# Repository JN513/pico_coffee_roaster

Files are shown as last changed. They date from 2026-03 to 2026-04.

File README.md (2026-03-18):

# Pico Coffee Roaster

Mini torrador de café baseado no Raspberry Pi Pico.

Este firmware é capaz de realizar o controle de uma resistência utilizando um triac, além do controle de um motor e de um fan via PWM.
Também estão disponíveis periféricos como displays, termistores NTC, termopares PT0, controle PID, entre outros.

O projeto utiliza o pico-sdk como base.
Além do pico-sdk instalado e configurado no PATH do ambiente, também é necessário instalar o pico-extras.

## Build e load

Para compilar o projeto utilize:

```bash
mkdir -p build
cd build
cmake ..
make -j$(nproc)
```

Para enviar o firmware para o Pico utilize:

```bash
cd build
picotool load pico_roster.uf2 -f
```

Certifique-se de que o `picotool` esteja instalado e disponível no PATH do sistema.

## Dúvidas e Sugestões

Se tiver alguma dúvida ou sugestão, sinta-se à vontade para utilizar a seção de [ISSUES](https://github.com/JN513/pico_coffee_roaster/issues) no GitHub. Contribuições são bem-vindas e todos os [Pull requests](https://github.com/JN513/pico_coffee_roaster/pulls) serão revisados e, se possível, mesclados.

## Contribuição

Se deseja contribuir com o projeto, sinta-se à vontade para fazê-lo. O arquivo [CONTRIBUTING.md](https://github.com/JN513/pico_coffee_roaster/blob/main/CONTRIBUTING.md) contém as instruções necessárias.

## Licença

Este projeto é licenciado sob a licença [MIT]([https://github.com/JN513/pico_coffee_roaster/blob/main/LICENSE](https://github.com/JN513/pico_coffee_roaster/blob/main/LICENSE)), que concede total liberdade para uso.

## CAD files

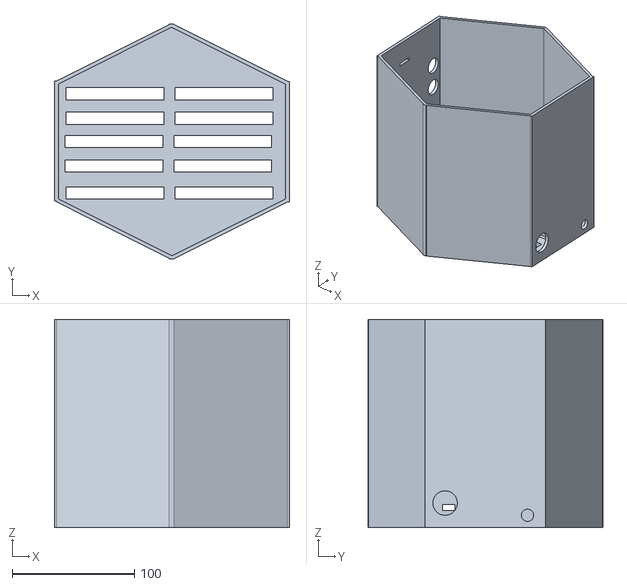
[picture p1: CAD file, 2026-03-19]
hardware/3d_models/roaster_case.stl
192.0 x 192.0 x 170.0

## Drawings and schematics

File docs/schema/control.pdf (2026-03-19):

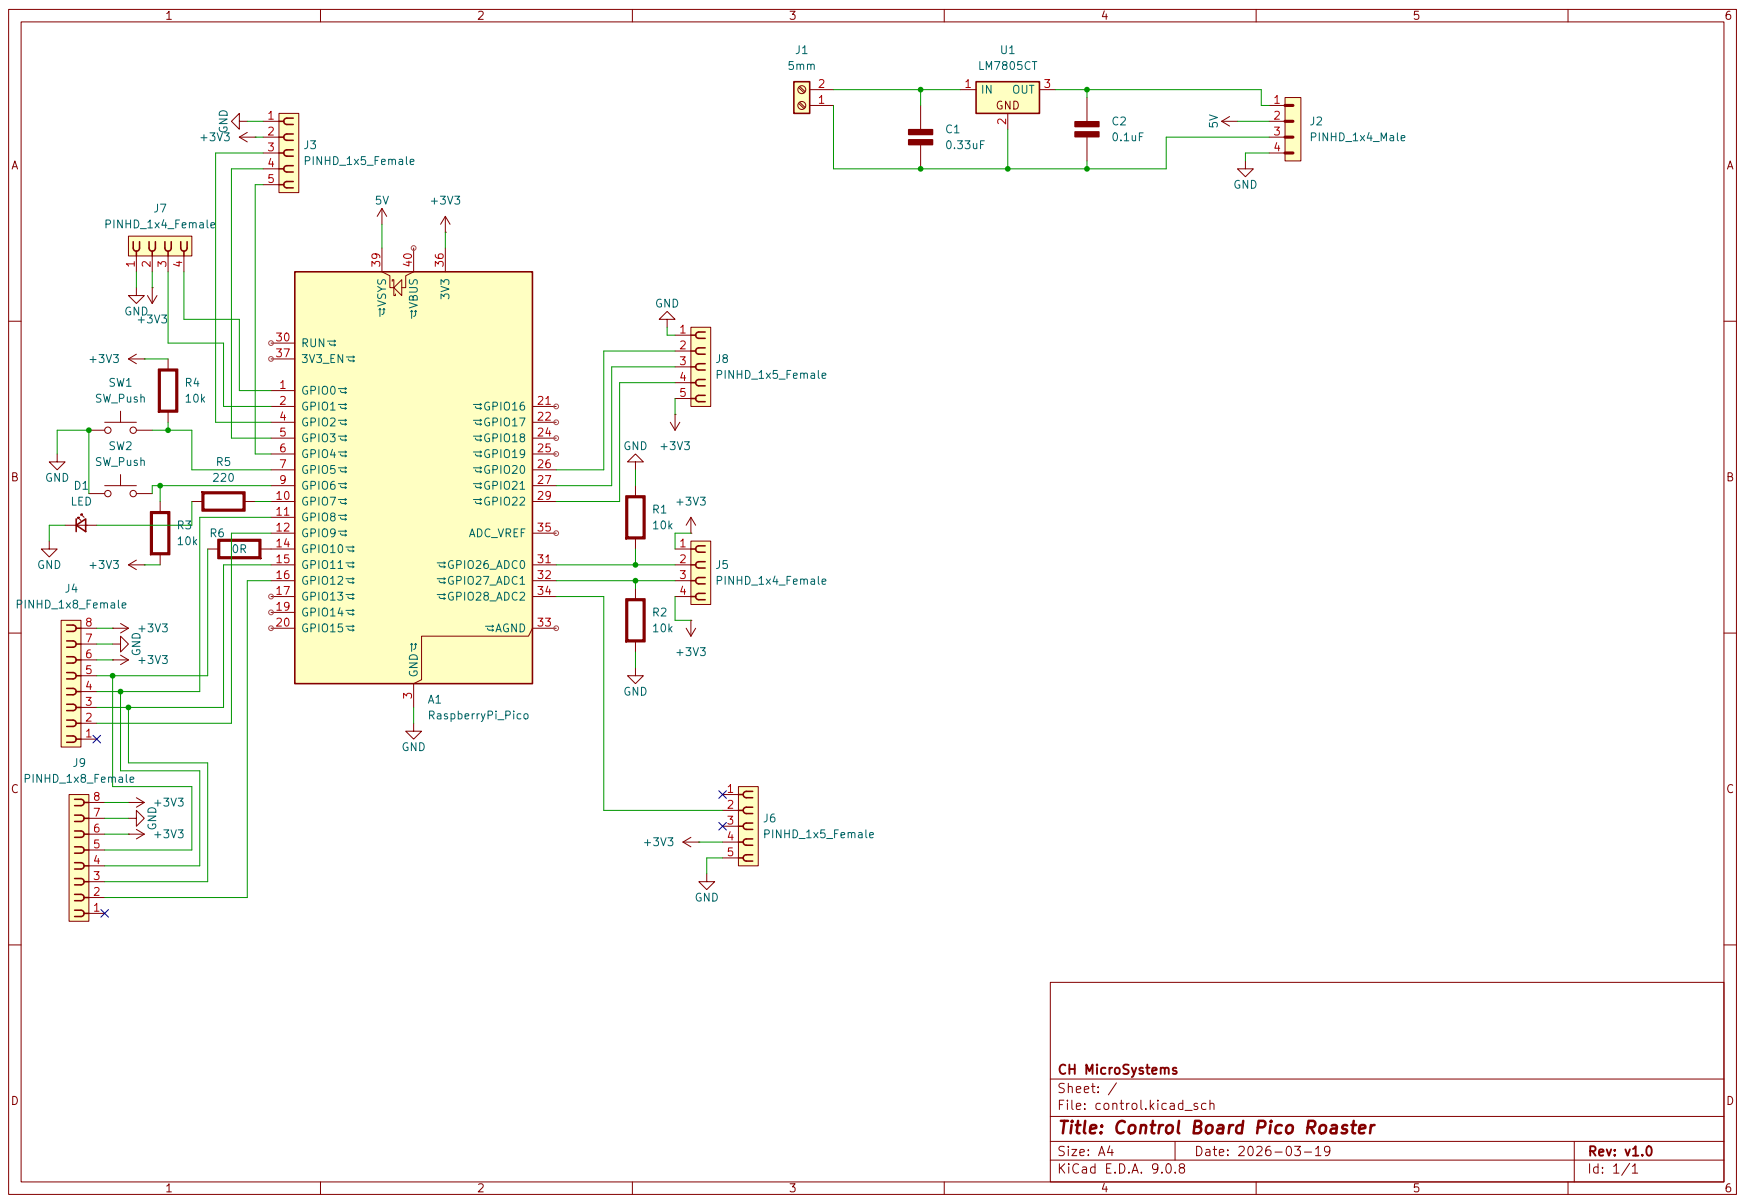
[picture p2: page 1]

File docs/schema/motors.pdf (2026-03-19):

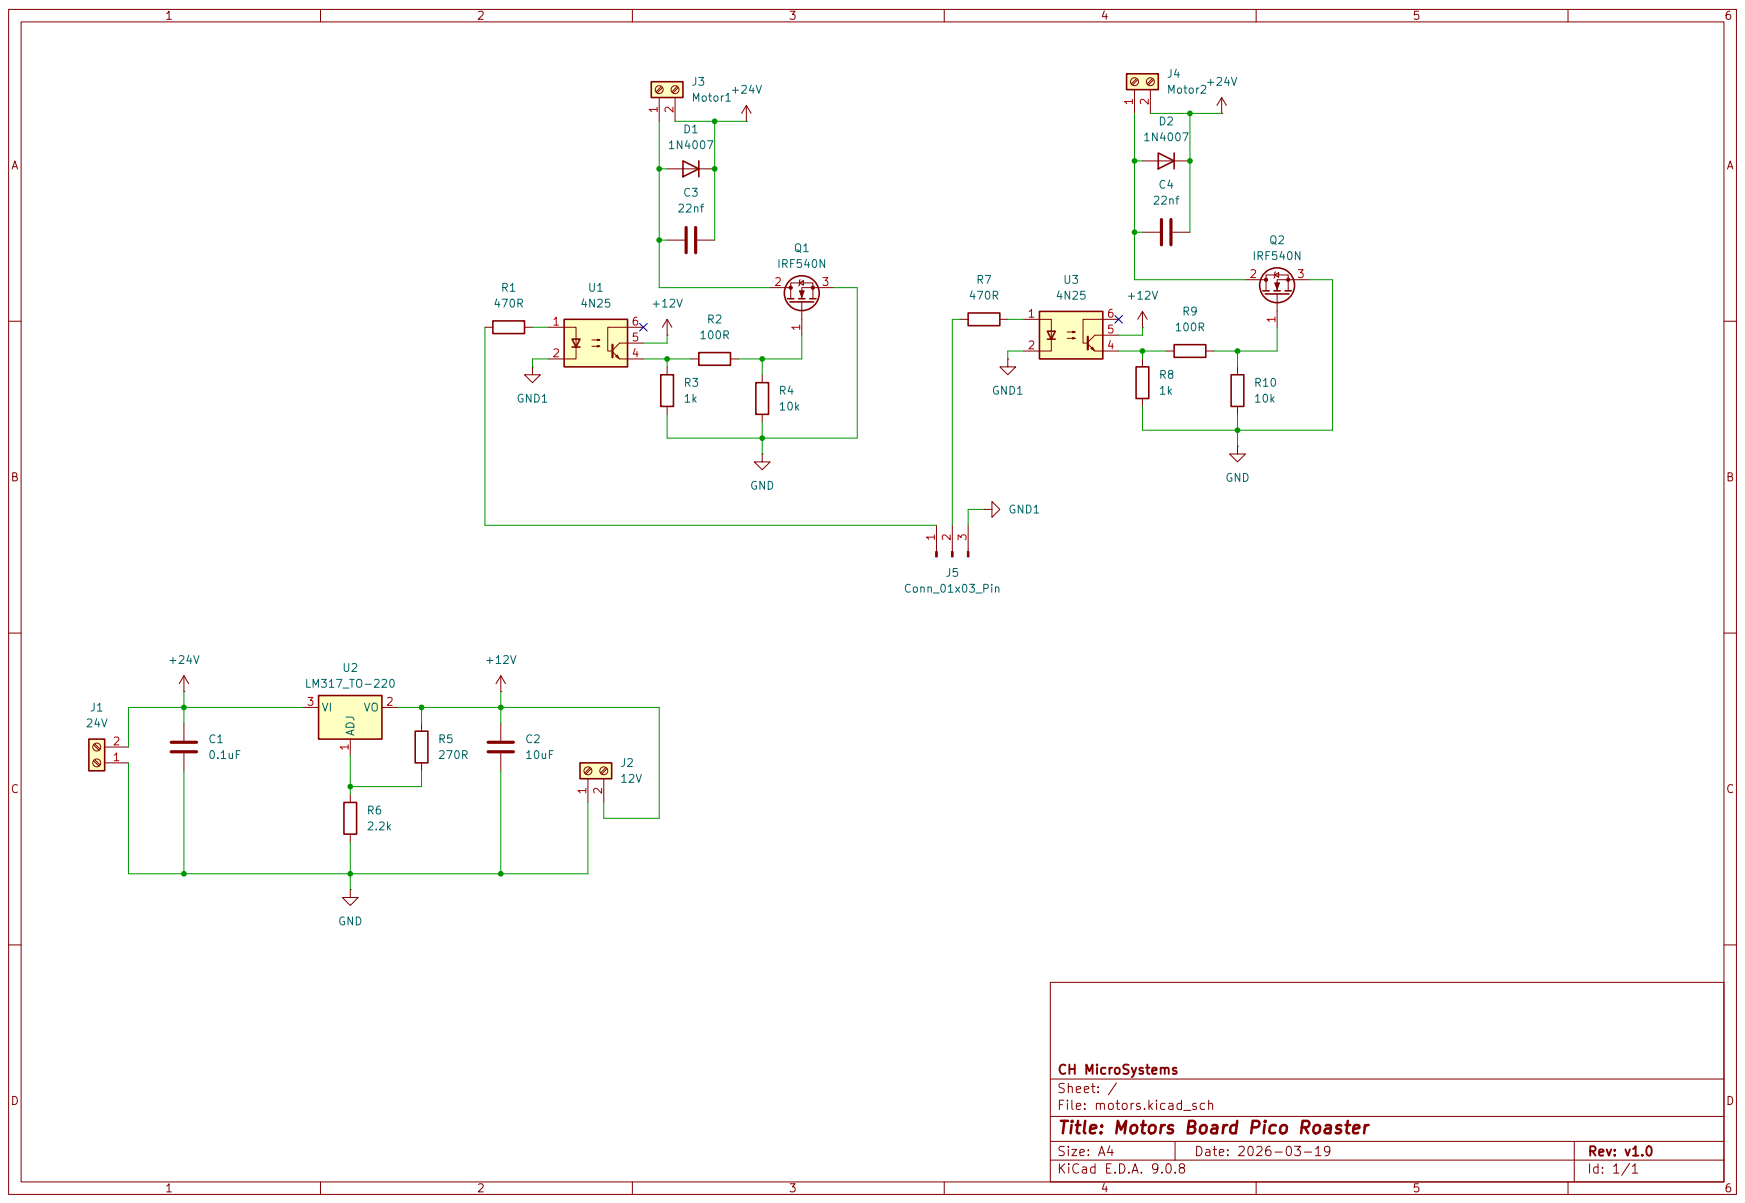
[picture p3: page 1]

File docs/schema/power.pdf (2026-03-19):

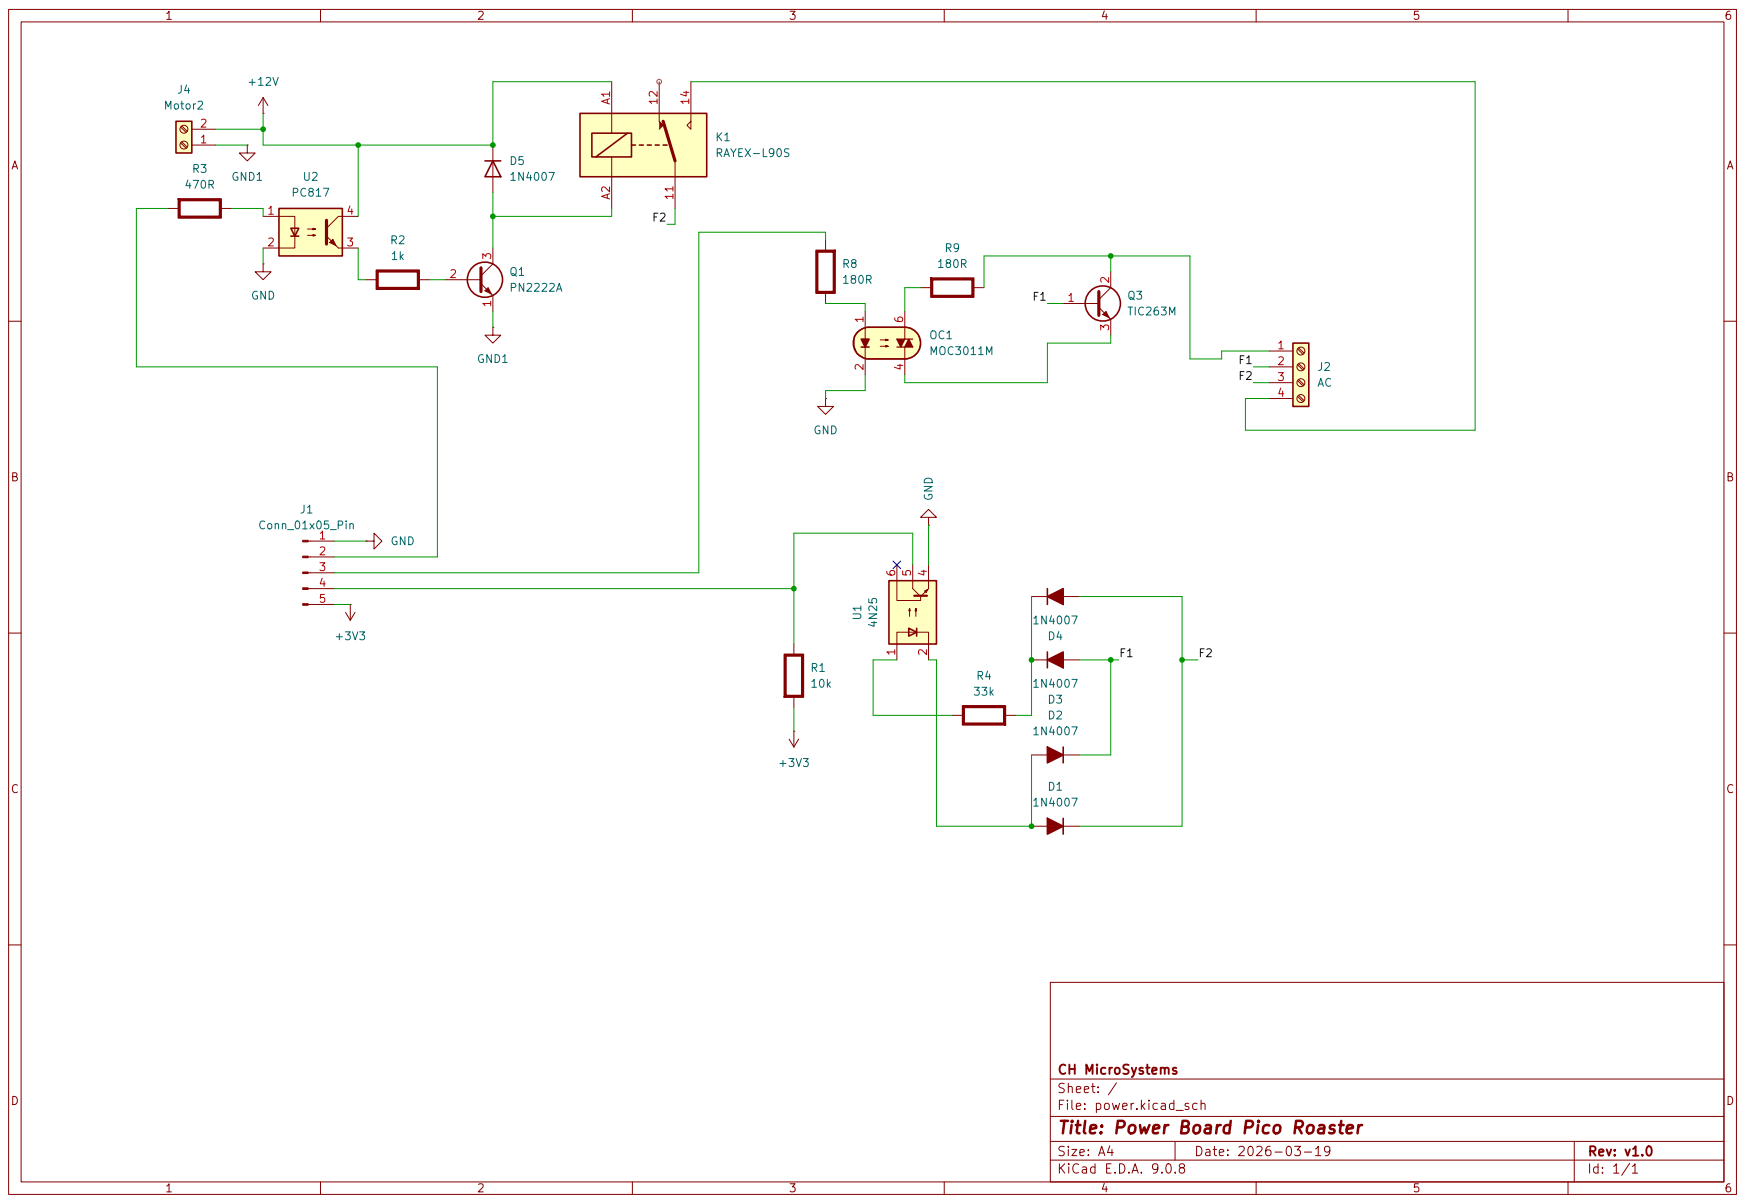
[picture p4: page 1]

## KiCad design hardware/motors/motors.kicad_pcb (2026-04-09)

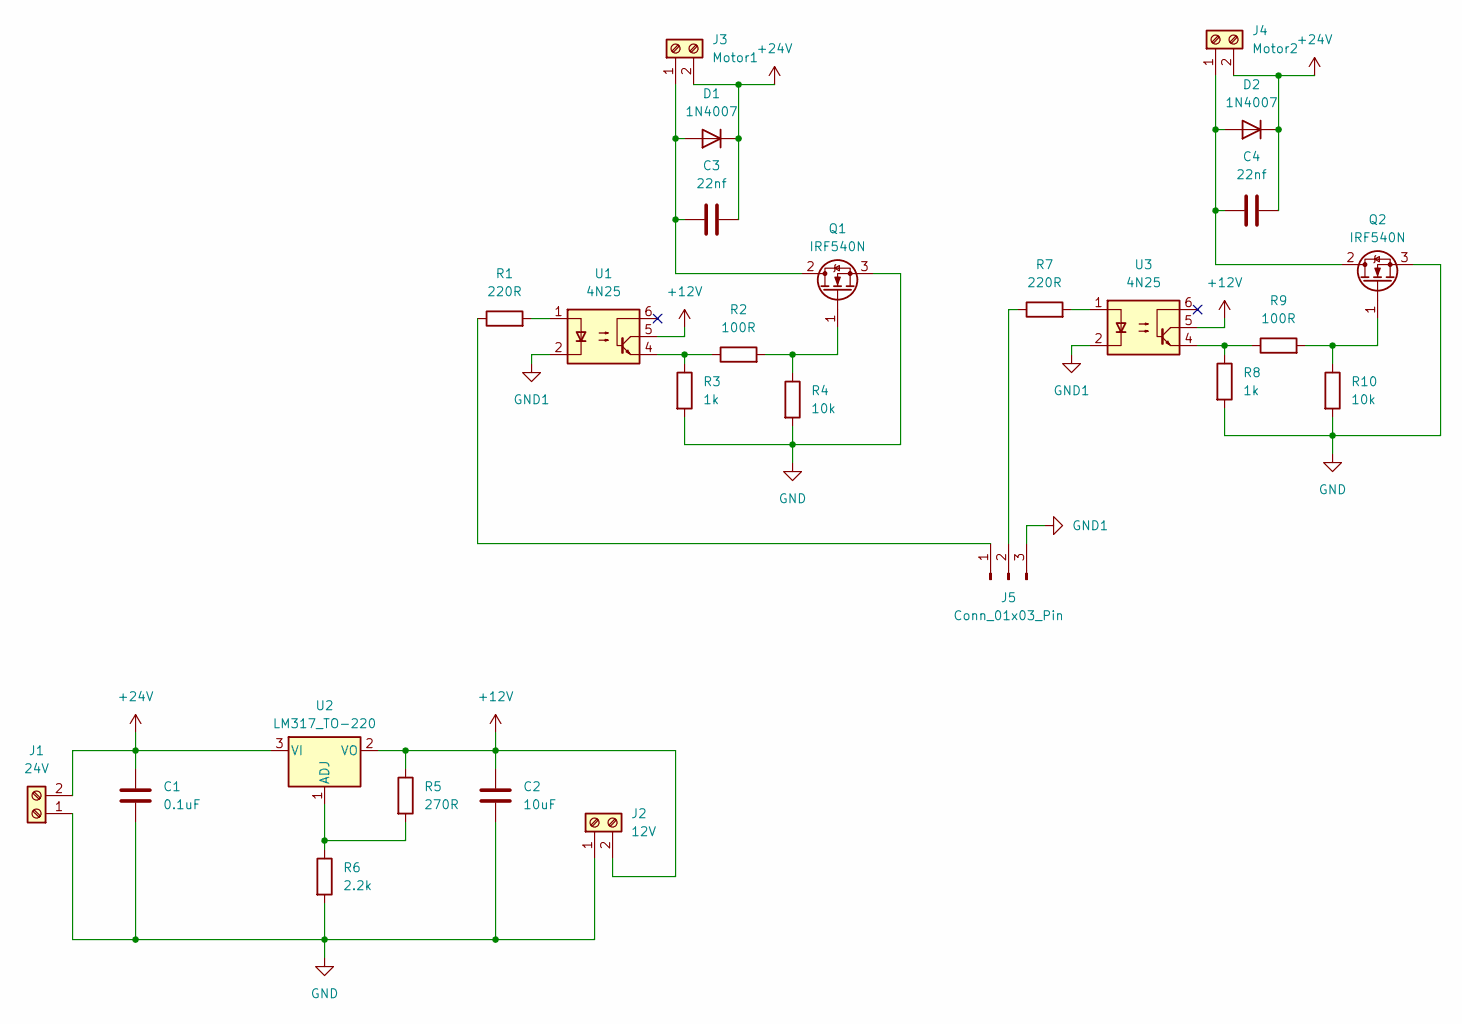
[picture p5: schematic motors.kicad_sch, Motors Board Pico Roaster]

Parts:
C1: 0.1uF; CP_Radial_D4.0mm_P2.00mm
C2: 10uF; CP_Radial_D4.0mm_P2.00mm
C3, C4: 22nf; C_Disc_D4.7mm_W2.5mm_P5.00mm
D1, D2: 1N4007; D_DO-41_SOD81_P10.16mm_Horizontal
J1: 24V; Altech_AK100_1x02_P5.00mm
J2: 12V; Altech_AK100_1x02_P5.00mm
J3: Motor1; Altech_AK100_1x02_P5.00mm
J4: Motor2; Altech_AK100_1x02_P5.00mm
J5: Conn_01x03_Pin; PinHeader_1x03_P2.54mm_Vertical
Q1, Q2: IRF540N; TO-220-3_Vertical
R1, R7: 220R; R_Axial_DIN0204_L3.6mm_D1.6mm_P7.62mm_Horizontal
R2, R9: 100R; R_Axial_DIN0204_L3.6mm_D1.6mm_P7.62mm_Horizontal
R3, R8: 1k; R_Axial_DIN0204_L3.6mm_D1.6mm_P7.62mm_Horizontal
R4, R10: 10k; R_Axial_DIN0204_L3.6mm_D1.6mm_P7.62mm_Horizontal
R5: 270R; R_Axial_DIN0204_L3.6mm_D1.6mm_P7.62mm_Horizontal
R6: 2.2k; R_Axial_DIN0204_L3.6mm_D1.6mm_P7.62mm_Horizontal
U1, U3: 4N25; DIP-6_W7.62mm
U2: LM317_TO-220; TO-220-3_Vertical

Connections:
+12V: C2.1, J2.2, R5.1, U1.5, U2.2 (VO), U3.5
+24V: C1.1, C3.2, C4.2, D1.1 (K), D2.1 (K), J1.2, J3.2, J4.2, U2.3 (VI)
GND: C1.2, C2.2, J1.1, J2.1, Q1.3 (S), Q2.3 (S), R3.2, R4.2, R6.2, R8.2, R10.2
GND1: J5.3, U1.2, U3.2
unnamed: C3.1, D1.2 (A), J3.1, Q1.2 (D)
unnamed: C4.1, D2.2 (A), J4.1, Q2.2 (D)
unnamed: J5.1, R1.1
unnamed: J5.2, R7.1
unnamed: Q1.1 (G), R2.2, R4.1
unnamed: Q2.1 (G), R9.2, R10.1
unnamed: R1.2, U1.1
unnamed: R2.1, R3.1, U1.4
unnamed: R7.2, U3.1
unnamed: R8.1, R9.1, U3.4
unnamed: R5.2, R6.1, U2.1 (ADJ)

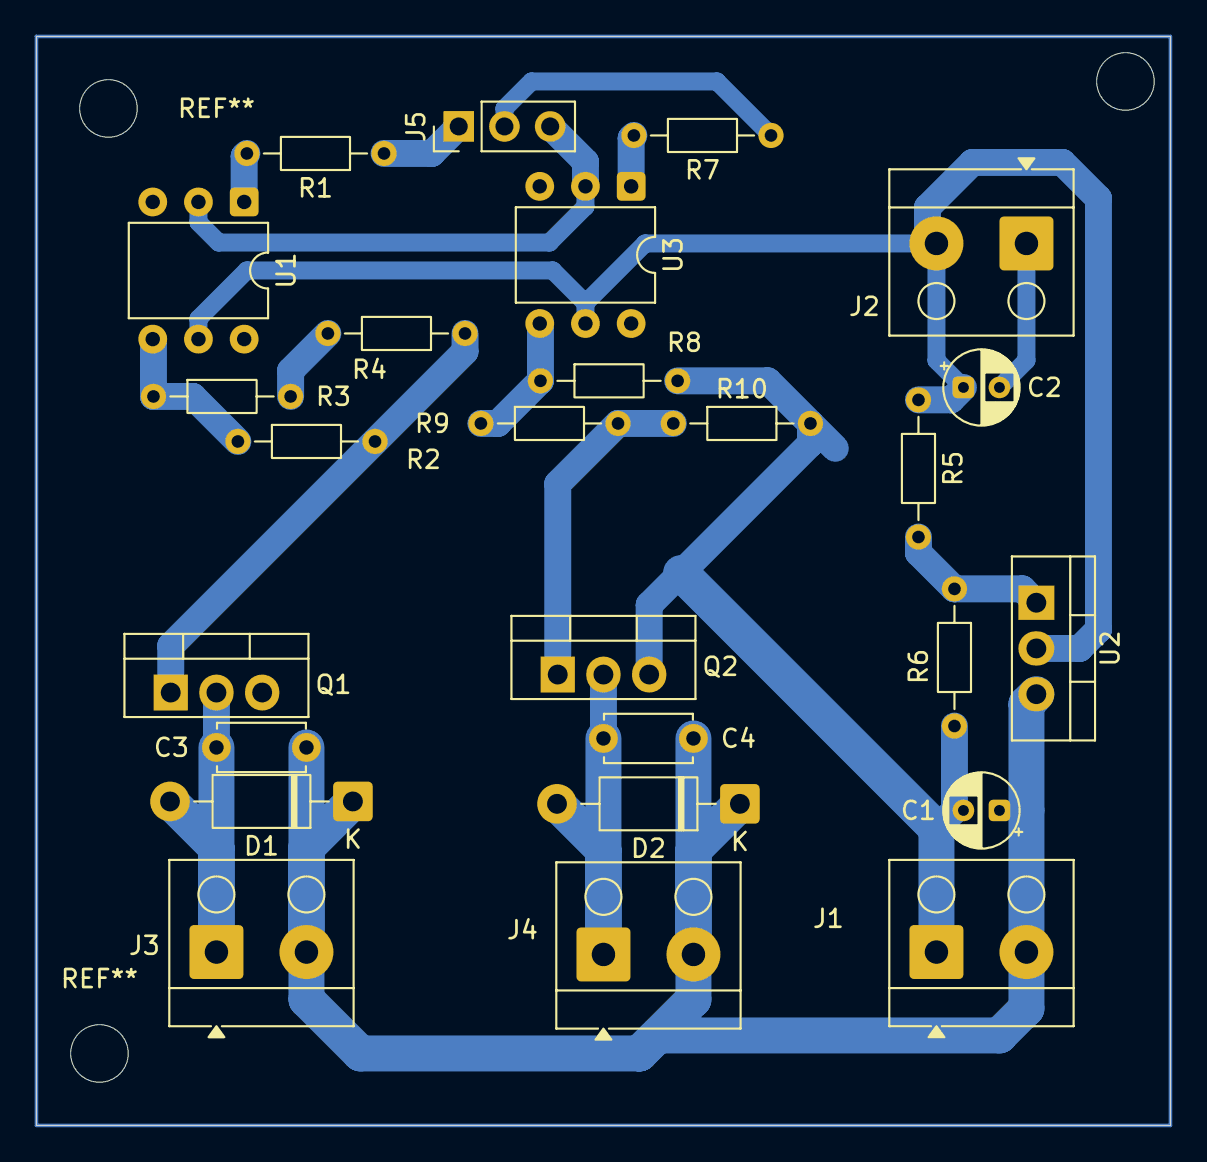
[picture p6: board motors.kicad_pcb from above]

Board: 2 copper layers, 63.0 x 60.5 mm, 26 parts (0 on the bottom side), 15 nets.

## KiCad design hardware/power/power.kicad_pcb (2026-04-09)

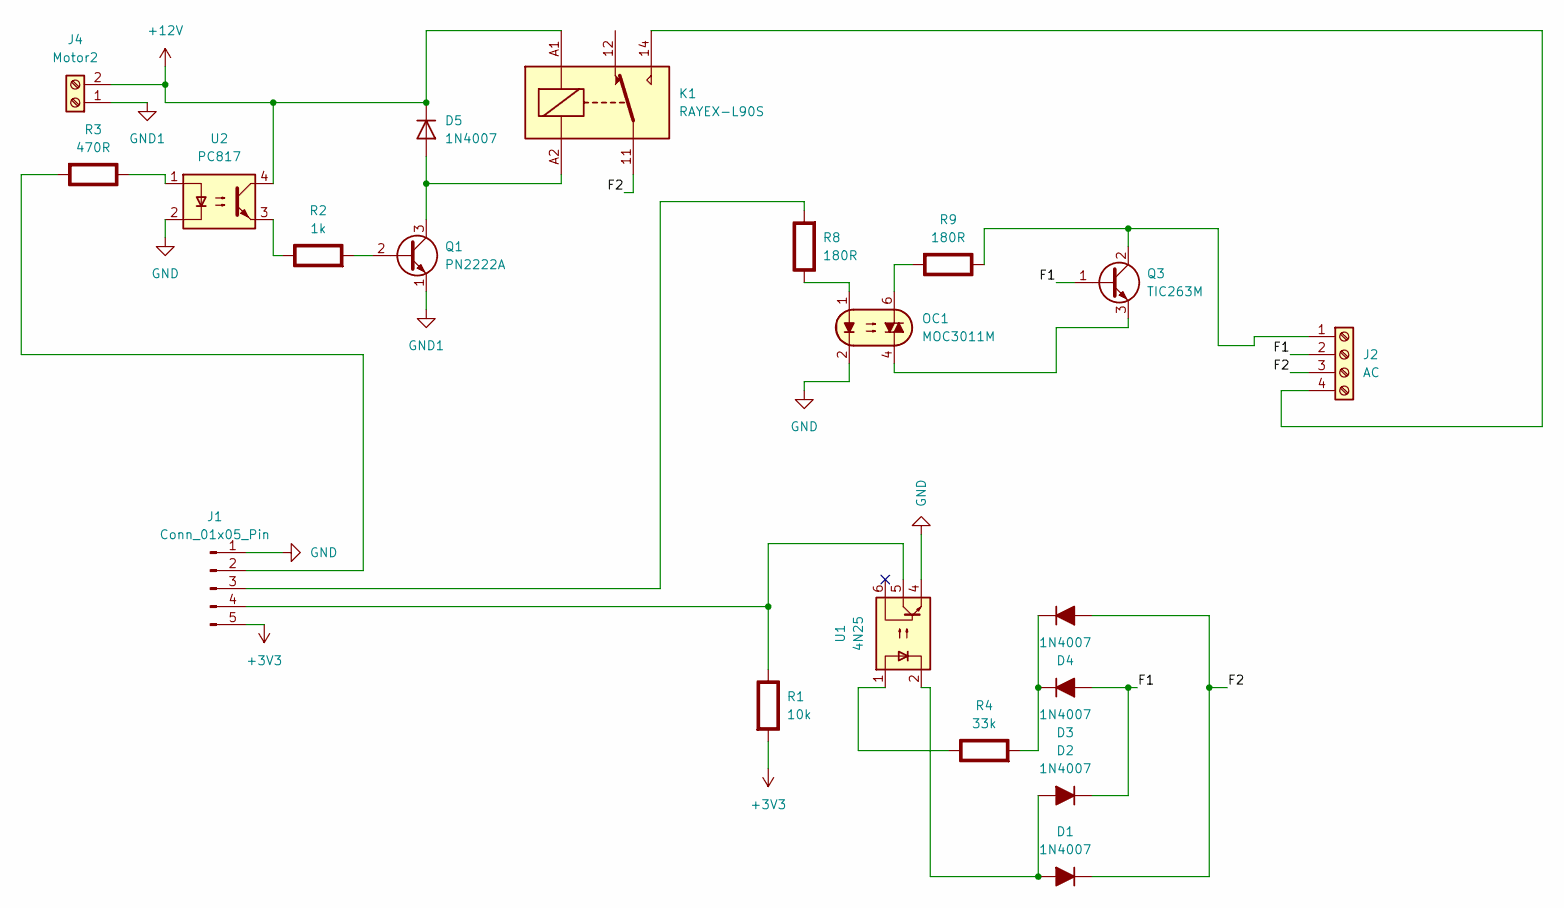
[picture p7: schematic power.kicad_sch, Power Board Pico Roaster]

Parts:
D1, D2, D3, D4, D5: 1N4007; D_DO-41_SOD81_P10.16mm_Horizontal
J1: Conn_01x05_Pin; PinHeader_1x05_P2.54mm_Vertical
J2: AC; Altech_AK100_1x04_P5.00mm
J4: Motor2; Altech_AK100_1x02_P5.00mm
K1: RAYEX-L90S; Relay_SPDT_RAYEX-L90S
OC1: MOC3011M; DIP-6_W7.62mm_LongPads
Q1: PN2222A; TO-92_Inline
Q3: TIC263M; TO-218-3_Vertical
R1: 10k; R_Axial_DIN0207_L6.3mm_D2.5mm_P10.16mm_Horizontal; Rating W
R2: 1k; R_Axial_DIN0207_L6.3mm_D2.5mm_P10.16mm_Horizontal; Rating W
R3: 470R; R_Axial_DIN0207_L6.3mm_D2.5mm_P10.16mm_Horizontal; Rating W
R4: 33k; R_Axial_DIN0207_L6.3mm_D2.5mm_P10.16mm_Horizontal; Rating W
R8: 180R; R_Axial_DIN0207_L6.3mm_D2.5mm_P10.16mm_Horizontal; Rating W
R9: 180R; R_Axial_DIN0414_L11.9mm_D4.5mm_P20.32mm_Horizontal; Rating W
U1: 4N25; DIP-6_W7.62mm
U2: PC817; DIP-4_W7.62mm

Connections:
+3V3: J1.5, R1.2 (-)
+12V: D5.1 (K), J4.2, K1.A1, U2.4
/F1: D2.1 (K), D3.2 (A), J2.2, Q3.1 (B)
/F2: D1.1 (K), D4.2 (A), J2.3, K1.11
GND: J1.1, OC1.2, U1.4, U2.2
GND1: J4.1, Q1.1 (E)
unnamed: D1.2 (A), D2.2 (A), U1.2
unnamed: D3.1 (K), D4.1 (K), R4.2 (-)
unnamed: D5.2 (A), K1.A2, Q1.3 (C)
unnamed: J1.2, R3.2 (-)
unnamed: J1.3, R8.2 (-)
unnamed: J1.4, R1.1 (+), U1.5
unnamed: J2.1, Q3.2 (C), R9.1 (+)
unnamed: J2.4, K1.14
unnamed: Q1.2 (B), R2.2 (-)
unnamed: OC1.4, Q3.3 (E)
unnamed: R2.1 (+), U2.3
unnamed: R3.1 (+), U2.1
unnamed: R4.1 (+), U1.1
unnamed: OC1.1, R8.1 (+)
unnamed: OC1.6, R9.2 (-)

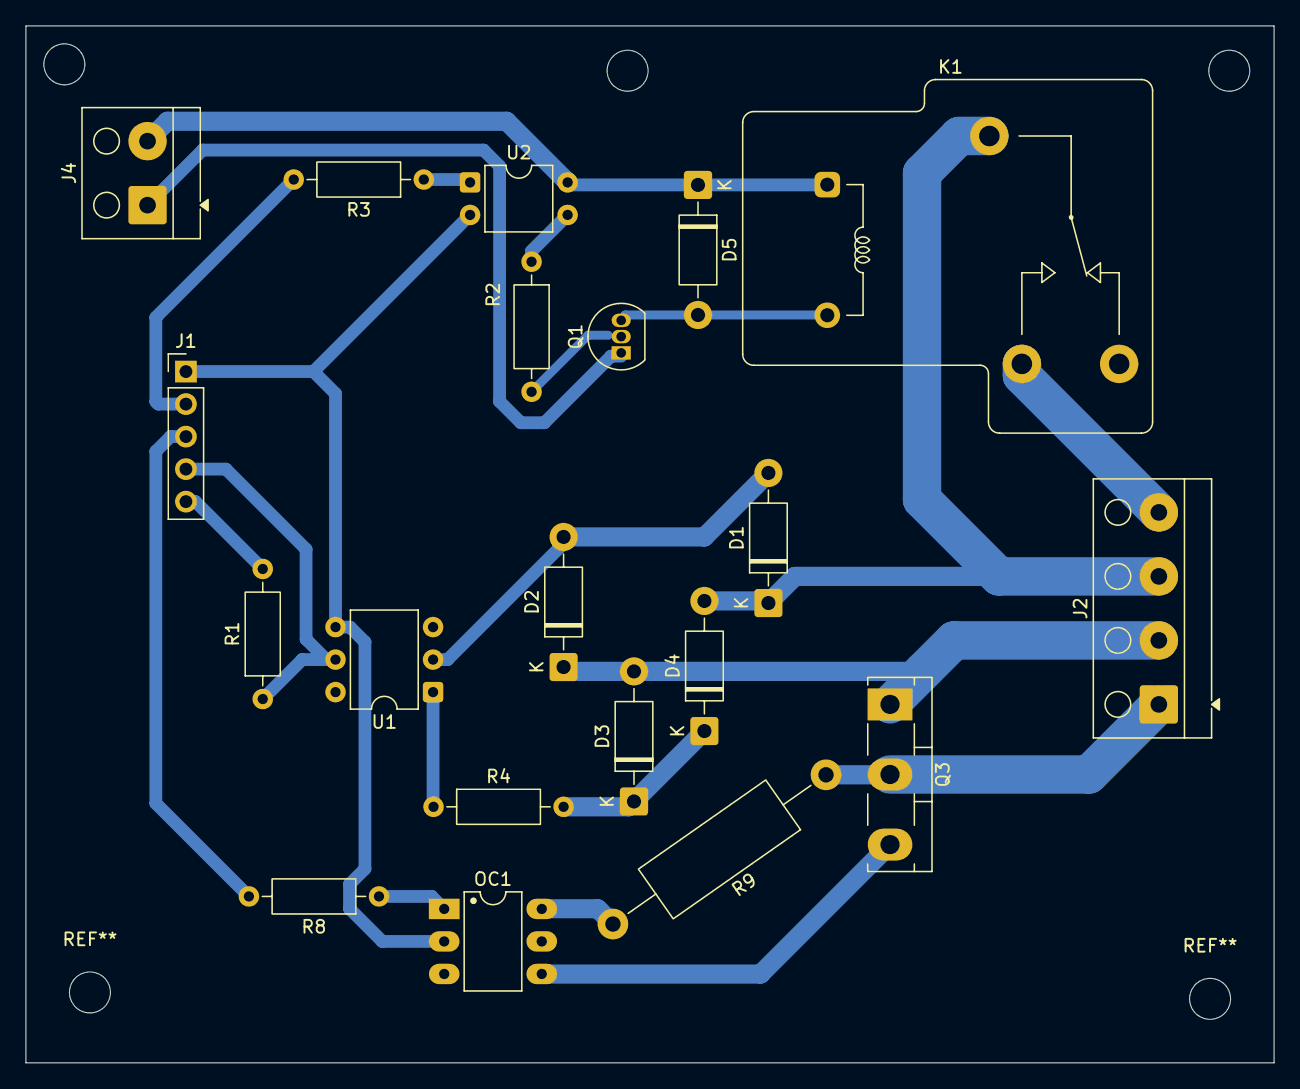
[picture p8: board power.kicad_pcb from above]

Board: 2 copper layers, 97.5 x 81.0 mm, 20 parts (0 on the bottom side), 21 nets.

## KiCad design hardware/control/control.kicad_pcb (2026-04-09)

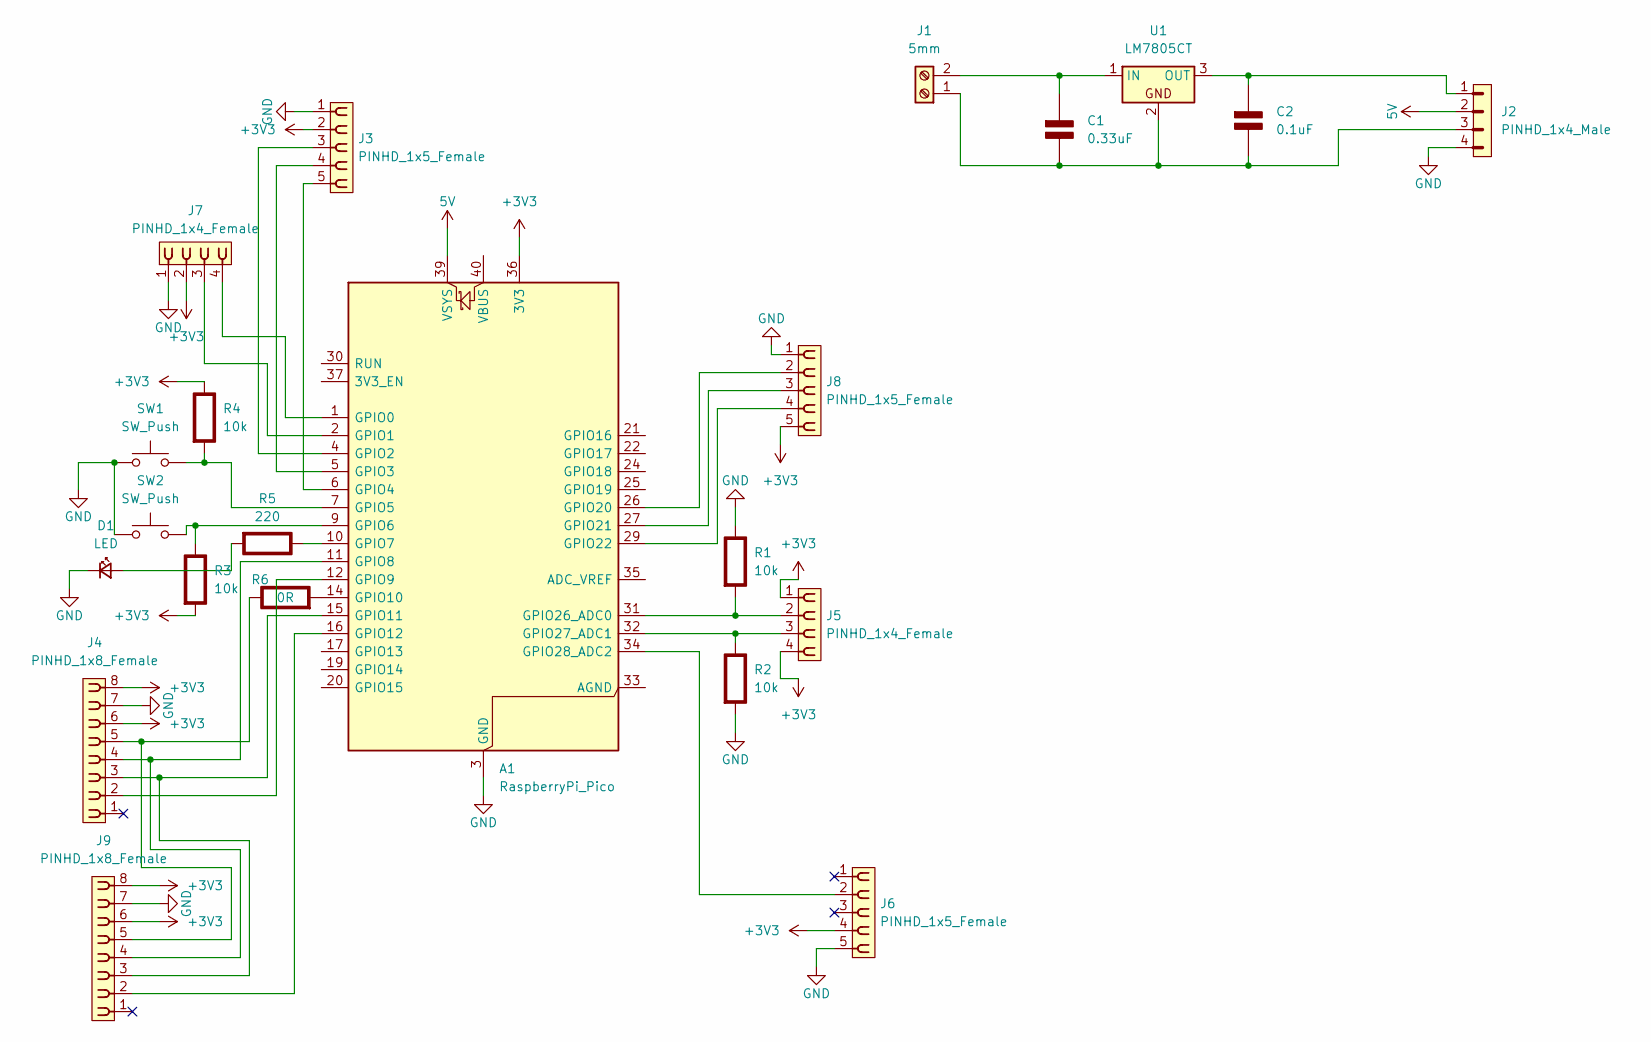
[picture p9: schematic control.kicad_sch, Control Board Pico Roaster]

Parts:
A1: RaspberryPi_Pico; RaspberryPi_Pico_Common_Unspecified
C1: 0.33uF; C_Radial_D5.0mm_H7.0mm_P2.00mm; Rating V
C2: 0.1uF; C_Radial_D5.0mm_H7.0mm_P2.00mm; Rating V
D1: LED; LED_D5.0mm
J1: 5mm; ScrewTerminal_1x02_P5.0mm
J2: PINHD_1x4_Male; PinHeader_1x04_P2.54mm_Vertical
J3, J6, J8: PINHD_1x5_Female; PinSocket_1x05_P2.54mm_Vertical
J4, J9: PINHD_1x8_Female; PinSocket_1x08_P2.54mm_Vertical
J5, J7: PINHD_1x4_Female; PinSocket_1x04_P2.54mm_Vertical
R1, R2, R3, R4: 10k; R_Axial_DIN0207_L6.3mm_D2.5mm_P10.16mm_Horizontal; Rating W
R5: 220; R_Axial_DIN0207_L6.3mm_D2.5mm_P10.16mm_Horizontal; Rating W
R6: 0R; R_Axial_DIN0207_L6.3mm_D2.5mm_P10.16mm_Horizontal; Rating W
SW1, SW2: SW_Push; SW_PUSH_1P1T_6x3.5mm_H4.3_APEM_MJTP1243
U1: LM7805CT; TO-220-3_Vertical

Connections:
5V: A1.39 (VSYS), J2.2
+3V3: A1.36 (3V3), J3.2, J4.6, J4.8, J5.1, J5.4, J6.4, J7.2, J8.5, J9.6, J9.8, R3.2 (-), R4.1 (+)
GND: A1.3 (GND), A1.8 (GND), A1.13 (GND), A1.18 (GND), A1.23 (GND), A1.28 (GND), A1.38 (GND), D1.1 (K), J2.4, J3.1, J4.7, J6.5, J7.1, J8.1, J9.7, R1.1 (+), R2.2 (-), SW1.1, SW2.1
unnamed: A1.1 (GPIO0), J7.4
unnamed: A1.2 (GPIO1), J7.3
unnamed: A1.4 (GPIO2), J3.3
unnamed: A1.5 (GPIO3), J3.4
unnamed: A1.6 (GPIO4), J3.5
unnamed: A1.7 (GPIO5), R4.2 (-), SW1.2
unnamed: A1.9 (GPIO6), R3.1 (+), SW2.2
unnamed: A1.10 (GPIO7), R5.1 (+)
unnamed: A1.11 (GPIO8), J4.4, J9.4
unnamed: A1.12 (GPIO9), J4.2
unnamed: A1.14 (GPIO10), R6.2 (-)
unnamed: A1.15 (GPIO11), J4.3, J9.3
unnamed: A1.16 (GPIO12), J9.2
unnamed: A1.26 (GPIO20), J8.2
unnamed: A1.27 (GPIO21), J8.3
unnamed: A1.29 (GPIO22), J8.4
unnamed: A1.31 (GPIO26_ADC0), J5.2, R1.2 (-)
unnamed: A1.32 (GPIO27_ADC1), J5.3, R2.1 (+)
unnamed: A1.34 (GPIO28_ADC2), J6.2
unnamed: C1.1 (+), J1.2, U1.1 (IN)
unnamed: C1.2 (-), C2.2 (-), J1.1, J2.3, U1.2
unnamed: C2.1 (+), J2.1, U1.3 (OUT)
unnamed: D1.2 (A), R5.2 (-)
unnamed: J4.5, J9.5, R6.1 (+)

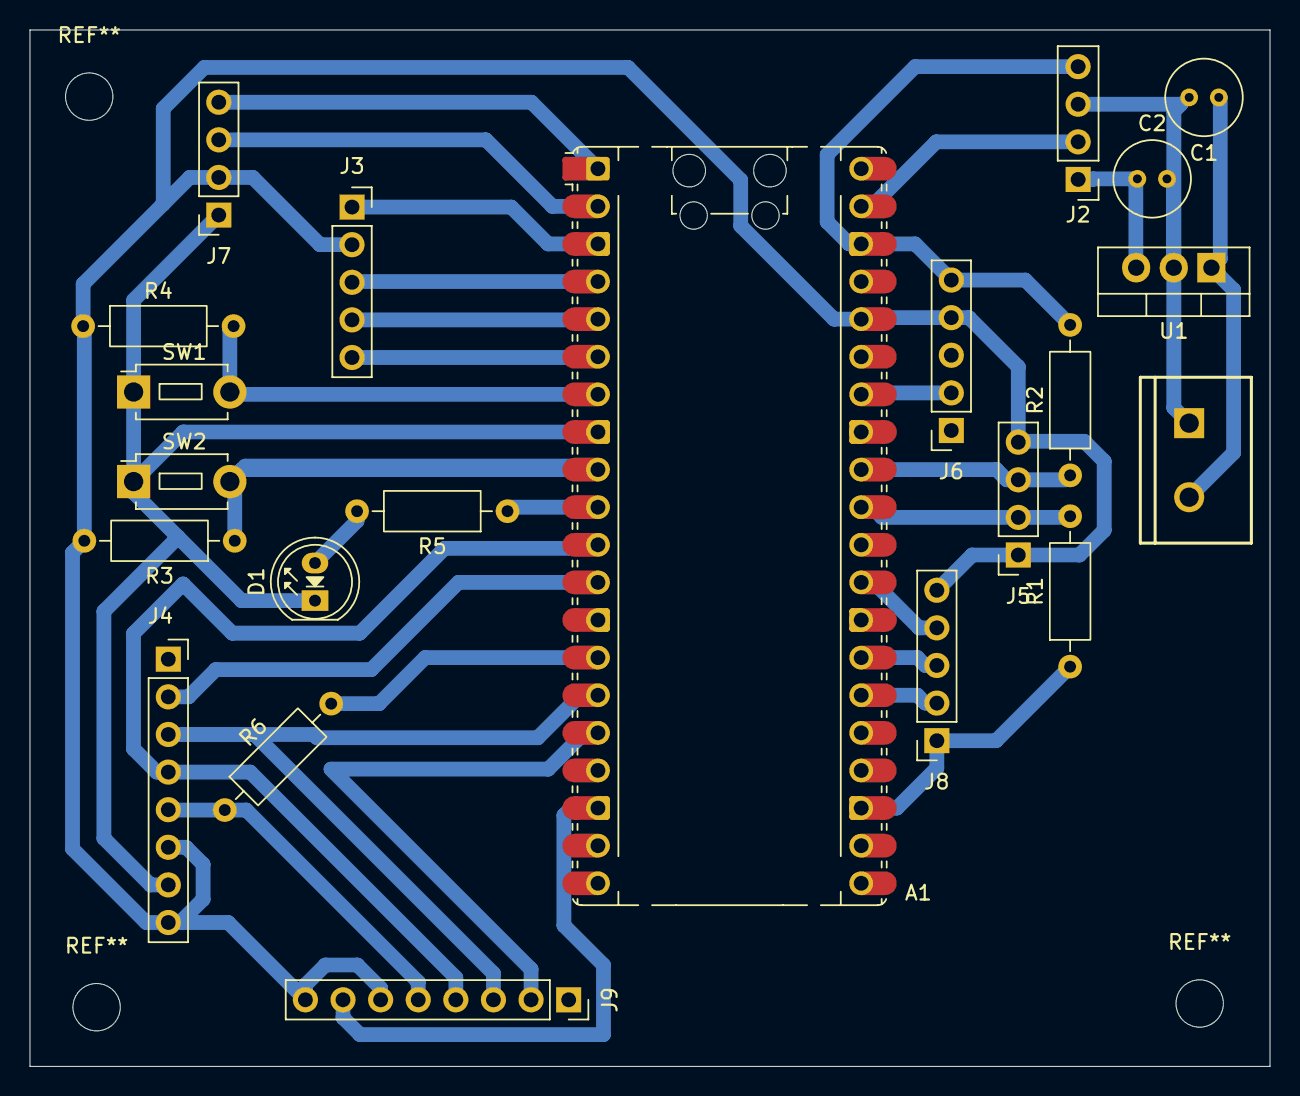
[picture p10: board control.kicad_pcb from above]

Board: 2 copper layers, 83.8 x 70.0 mm, 22 parts (0 on the bottom side), 27 nets.

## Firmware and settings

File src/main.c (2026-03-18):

#include <stdio.h>
#include "config.h"
#include "pico/stdlib.h"
#include "pico/multicore.h"
#include "system_state.h"

// Free RTOS
#include "FreeRTOS.h"
#include "task.h"
#include "queue.h"


extern QueueHandle_t encoderQueue;
extern uint32_t millis();
extern void core1_main();
extern void TaskDisplay_Control(void *p);
extern void TaskArtisan_uart(void *p);
extern void TaskUi(void *p);
extern void TaskEncoder(void *p);

int main () {
    stdio_init_all();

    sleep_ms(2000);

    encoderQueue = xQueueCreate(ENCODER_QUEUE_SIZE, sizeof(int));
    if (!encoderQueue) panic("encoderQueue");

    multicore_launch_core1(core1_main);
    xTaskCreate(TaskEncoder, "encoder", UI_TASK_STACK_SIZE, NULL, UI_TASK_PRIORITY, NULL);
    xTaskCreate(TaskDisplay_Control, "display", DISPLAY_STACK_SIZE, NULL, DISPLAY_TASK_PRIORITY, NULL);
    xTaskCreate(TaskArtisan_uart, "artisan", ARTISAN_STACK_SIZE, NULL, ARTISAN_TASK_PRIORITY, NULL);
    xTaskCreate(TaskUi, "ui_control", UI_TASK_STACK_SIZE, NULL, UI_TASK_PRIORITY, NULL);
    //xTaskCreate(TaskFC, "fc", 2048, NULL, 1, NULL);
    vTaskStartScheduler();

    // se chegar aqui, erro
    printf("Erro: scheduler retornou\n");
    while (1) tight_loop_contents();
    return 0;
}

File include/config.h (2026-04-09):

#ifndef __CONFIG_H__
#define __CONFIG_H__

// --- Configurações de Hardware ---
#define ADC_PIN_A             26 // Termistor A (ET)
#define ADC_PIN_B             27 // Termistor B (BT)
#define MOTOR_PIN             19 // 22
#define ZERO_PHASE_DETECT_PIN 22 // 21
#define TRIAC_PIN             21 // 20

// --- Calibragem do Thermistor ---
#define SERIES_RESISTOR       10000.0f  
#define NOMINAL_RES           100000.0f  
#define NOMINAL_TEMP          25.0f
#define BETA                  3950.0f

#define ALPHA                 0.2 // Fator de suavização do filtro irr da temperatura

#define MAX_PIN_SCK           10
#define MAX_PIN_MOSI          11
#define MAX_PIN_MISO          8
#define MAX_PIN_CS            9
#define MAX_PIN_RDY           14

#define RELEY_PIN             20 // 18
#define FAN_PIN               18

#define BTN1_PIN              5 // 3
#define BTN2_PIN              6

#define ENCODER_BTN_PIN       2 // 2
#define ENCODER_DT_PIN        3 // 4
#define ENCODER_CLK_PIN       4 // 5

#define OLED_SDA_PIN          0
#define OLED_SCL_PIN          1

#define PRE_HEAT_DURATION     60 // Duração do pré-aquecimento em segundos
#define PRE_HEAT_TEMP         150 // Temperatura alvo para o pré-aquecimento

#define CONTROL_INTERVAL_MS   200 // Intervalo de controle em milissegundos

#define MAX_TEMP              250 // Temperatura máxima de segurança

#define COOLDOWN_MIN_TEMP     35

#define DISPLAY_STACK_SIZE    1024
#define ARTISAN_STACK_SIZE    1024
#define UI_TASK_STACK_SIZE    512 

#define DISPLAY_TASK_PRIORITY 2
#define ARTISAN_TASK_PRIORITY 4
#define UI_TASK_PRIORITY      3 

#define ENCODER_QUEUE_SIZE    10
#define ENCODER_DEBOUNCE_TIME 10000

#define KP                    2.0 // 3.5
#define KI                    0.005 // 0.02
#define KD                    1.0 // 2.0

#define FFT_SIZE              256
#define MICROPHONE_PIN        28

#endif // !__CONFIG_H__

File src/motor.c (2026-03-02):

#include <stdio.h>
#include <string.h>
#include "config.h"
#include "motor.h"
#include "pico/stdlib.h"
#include "hardware/pwm.h"


uint slice_num;
//const uint16_t WRAP = 2500;   // ~5 kHz
const uint16_t WRAP = 12500;   // ~1 kHz

void init_motor(){
    gpio_set_function(MOTOR_PIN, GPIO_FUNC_PWM);

    slice_num = pwm_gpio_to_slice_num(MOTOR_PIN);

    pwm_config config = pwm_get_default_config();

    pwm_config_set_clkdiv(&config, 10.0f);
    pwm_config_set_wrap(&config, WRAP);

    pwm_init(slice_num, &config, true);

    pwm_set_gpio_level(MOTOR_PIN, 0);
}

void set_motor_power(unsigned int percent) {
    if (percent > 100) percent = 100;

    // zona morta típica de 24V
    //if (percent > 0 && percent < 15)
    //    percent = 15;

    uint16_t level = (percent * WRAP) / 100;

    pwm_set_gpio_level(MOTOR_PIN, level);
}

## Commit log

2026-02-03 Implementando funcoes para controle
    Implementando funcoes para controle de potencia do motor via PWM, de
    resistencia via triac e leitura dos thermistores
2026-02-03 Usando timer temporariamente
2026-03-02 Implementando suporte para o Max31865
2026-03-15 Adicionando sistemas de profiles
2026-03-16 Atualizando auto poweroff
2026-03-17 Implementando sistema de Menu
2026-03-17 Implementando logica inicial de detector de first crack
    [config.h, fc_detector.c, main.c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]
2026-03-17 Corrigindo comportamento do encoder
    [main.c, system_rotines.c]
2026-03-18 Corrigindo parametros de controle
    [config.h, display.c, main.c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]
2026-03-18 Removendo logica separada para encoder
2026-03-18 Adicionando curva do PID os dados enviados ao Artisan
2026-03-19 Adicionando esquematicos ao projeto
    [control.kicad_pcb, control.kicad_sch, motors.kicad_pcb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]
2026-03-19 Adicionando case do torrador
    [roaster_case.stl]
2026-03-19 Removendo arquivos indesejados
    [motors-NPTH.drl, motors-PTH.drl]
2026-04-09 Adicionando perfil de amendoim
    [control.kicad_pcb, motors.kicad_pcb, motors.kicad_sch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]
